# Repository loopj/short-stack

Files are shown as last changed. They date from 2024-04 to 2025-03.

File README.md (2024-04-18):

<div align="center">
  <h1>
    Short Stack
    Short Stack
  </h1>

  <h4>World's Smallest Nintendo Wii, using a trimmed motherboard and custom stacked PCBs</h4>

  <p>
    <a href="#features">Features</a> &middot;
    <a href="#size--scale">Size & Scale</a> &middot;
    <a href="#components">Components</a> &middot;
    <a href="#build-guide">Build Guide</a> &middot;
    <a href="#special-thanks">Special Thanks</a>
  </p>
</div>

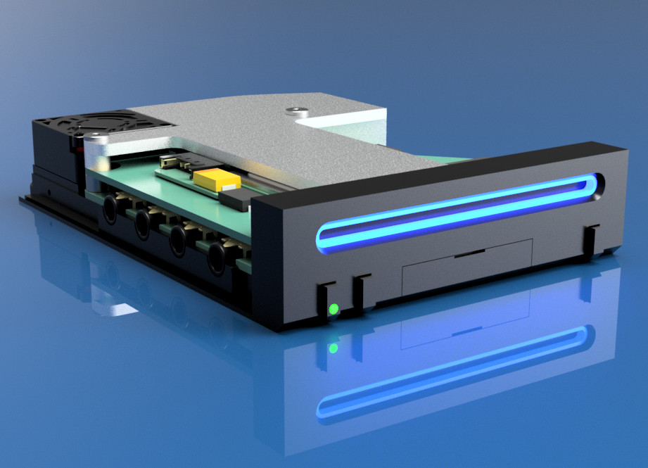
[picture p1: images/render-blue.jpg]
Short Stack Render


## Features

- World's smallest "to scale" Wii console
- Powered by USB-C
- HDMI for lossless digital audio and video (powered by [GCVideo](https://github.com/ikorb/gcvideo))
- Bluetooth for Wii remotes and accessories
- MicroSD card stores games and saves, instead of disc drive & memory cards
- 4 GameCube controller ports
- Power, reset, and sync buttons
- Power indicator LED and iconic blue glowing disc slot
- Soft shutdown, power on/off via Wiimote

## Size & Scale

This is a **1:2.38 scale** model of an original Nintendo Wii console, but since that is hard to visualize here are some other stats:

- Same size as a typical deck of playing cards
- **7.4% the volume** of an original Wii console
- You could fit **13.5** of these inside an original Wii

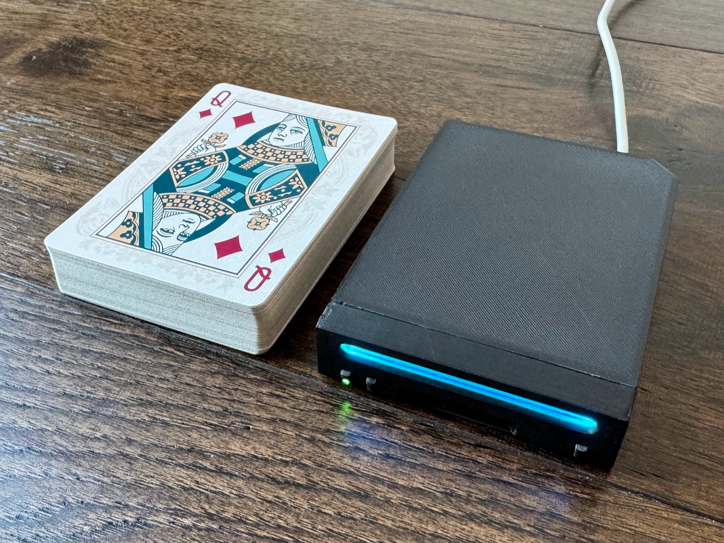
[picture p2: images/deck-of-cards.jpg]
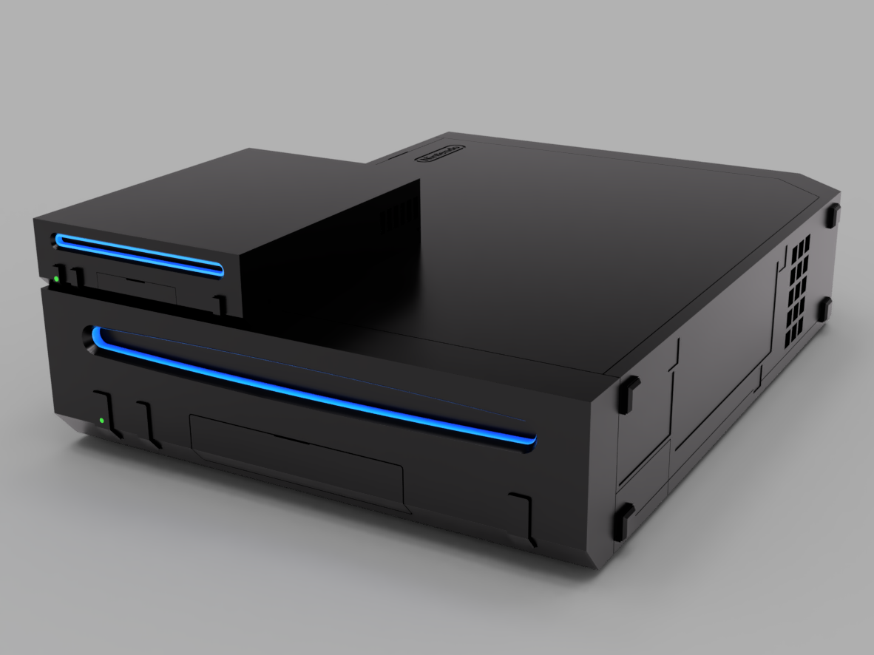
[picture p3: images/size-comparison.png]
 

I'm pretty sure this sets the record for the smallest functional scale-model Wii console, but let me know if I'm wrong!

### Could we go smaller?

Yes! It is definitely possible to go smaller than this. My [version of the Omega trim](images/trim.png) keeps all four main mounting holes, which makes it around 7mm wider than a classic Omega trim. Additionally [Wesk](https://twitter.com/Weskmods) has managed to get a Wii motherboard down to 52x52mm on his final destination trim, which is a a full 10mm narrower than my trim. I estimate you could reduce the volume by a further 25-30% without losing any functionality, but it would be an incredibly tight fit and tricky to assemble.

## Components

As the name implies, *Short Stack* is built from a stack of custom PCBs, and a custom heatsink, that are all designed to fit together in a compact and modular way.

### A modular motherboard

Making a tiny build like this is made possible by trimming the Wii motherboard down to the bare essentials. The result is a board which is just *62x62mm*, but still contains the CPU, GPU, RAM and flash memory.

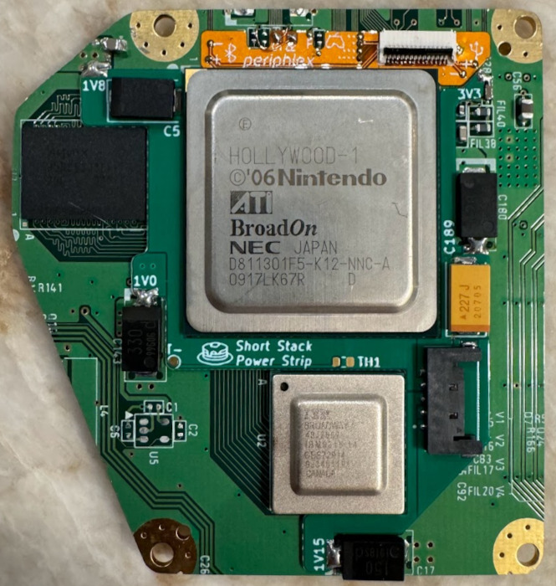
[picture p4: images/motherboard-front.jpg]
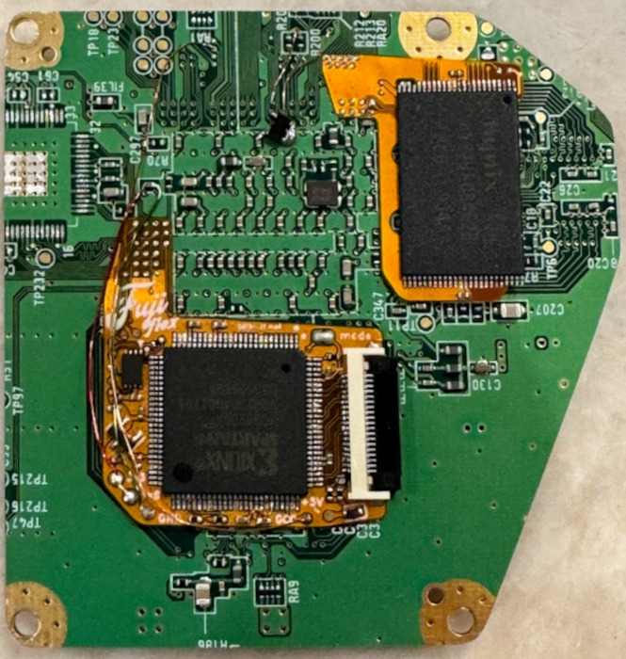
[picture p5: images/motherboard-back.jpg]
 

Since we removed the original power circuitry and trimmed off the USB, Bluetooth, and GameCube connectors, we need to provide power and data to the board another way. I designed a couple of boards which solder directly to the front of a trimmed Wii motherboard to provide power and data, which help avoid a tangled mess of wires.

The [Wii Power Strip](https://github.com/loopj/wii-power-strip) supplies power to the Wii motherboards using a Molex Pico-Lock connector, and additionally has footprints to help relocate of a couple of capacitors which are typically removed when trimming a Wii.

[Periphlex](https://github.com/loopj/periphlex) is a flex PCB which breaks out the Bluetooth, USB and GameCube controller data lines, as well as the power, shutdown, and reset GPIOs. These are then made available via a 14-pin FFC connector. This approach replaces 11 magnet wires with a single, removable ribbon cable.

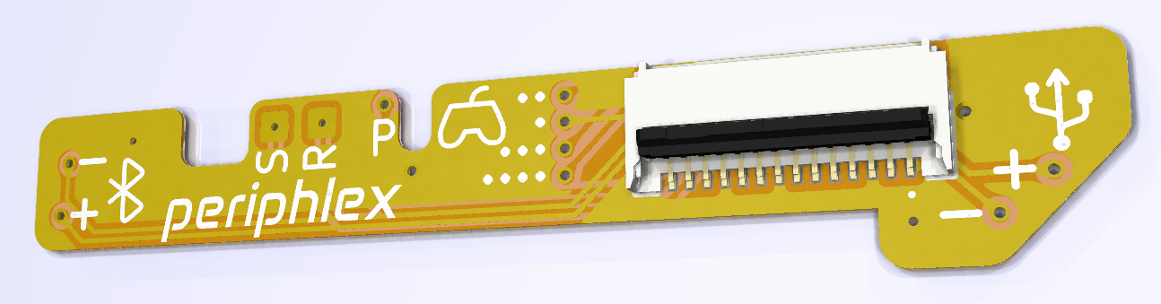
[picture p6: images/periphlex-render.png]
Periphlex


On the back of the motherboard, I'm using two open-source boards designed by the very talented [YveltalGriffin](https://github.com/mackieks). [fujiflex](https://github.com/mackieks/fujiflex) provides digital A/V output using GCVideo, and [nandFlex](https://github.com/mackieks/nandFlex) relocates the Wii's NAND memory chip, to enable the tight trim.

### Custom PCBs

In addition to the modular boards on the motherboard, I designed two PCBs specific to Short Stack which provide the rest of the functionality for the console.

The *main board* PCB hosts the power regulators, USB to microSD logic, HDMI connector, GameCube ports, and a microcontroller for power management. A 14-pin ribbon cable connects this board to the Wii motherboard via *Periphlex*, and a power cable delivers power to the *Power Strip*.

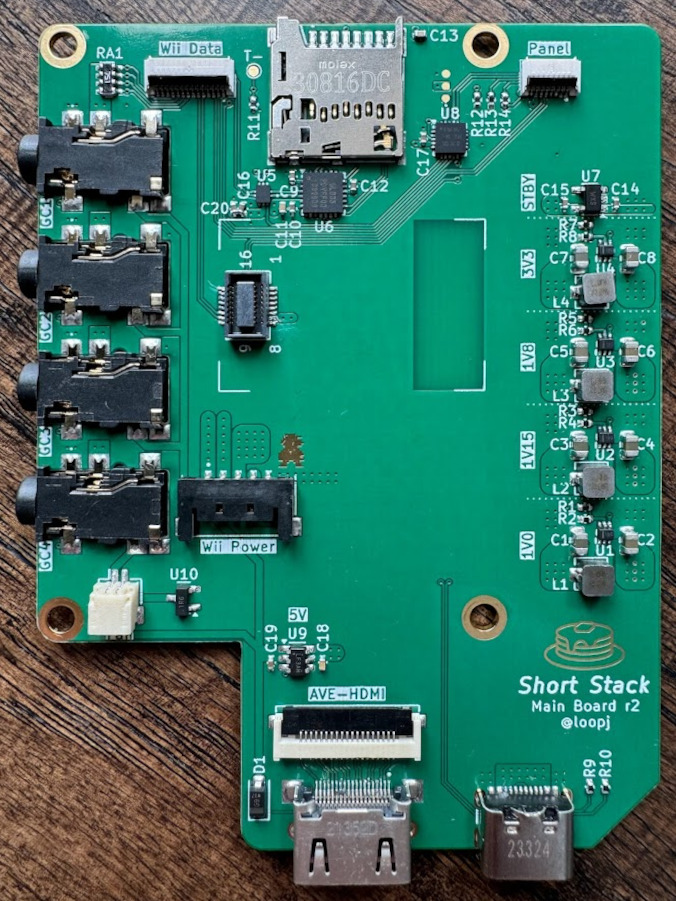
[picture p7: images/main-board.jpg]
Main Board


The *front panel* PCB hosts the power, reset, and sync buttons, as well as the power LED and disc slot LEDs. This board connects to the main board via a short 8-pin ribbon cable.

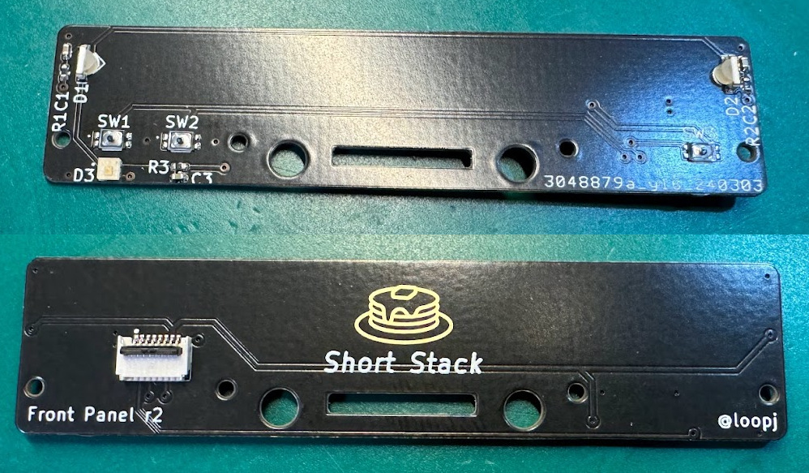
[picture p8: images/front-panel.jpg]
Front Panel Board


Since the GameCube controller connectors on the original Wii wouldn't fit cleanly on a build of this size, I use TRRS headphone connectors instead. This is the exact same approach used on the amazing [GC Nano](https://bitbuilt.net/forums/index.php?threads/gc-nano-the-worlds-smallest-gamecube.5697/) and in fact I made sure the dongles are pinout compatible!

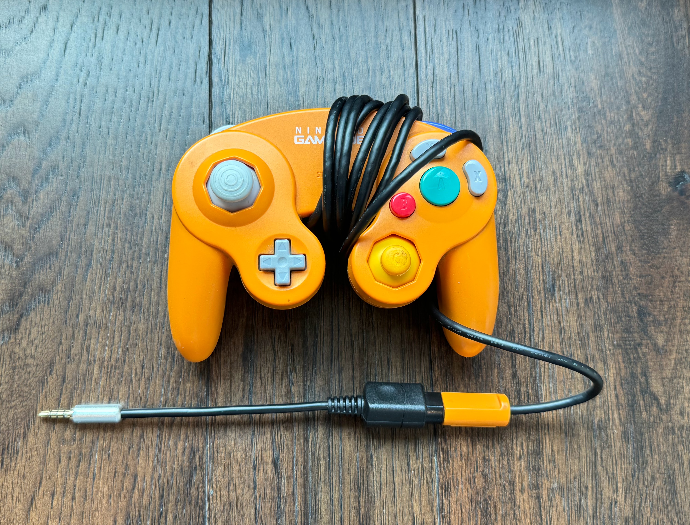
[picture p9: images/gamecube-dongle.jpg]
GameCube dongle


### Cooling

The final part of the "stack" is a custom heatsink which is designed to be as low profile as possible, while still providing adequate cooling for the Wii's CPU and GPU. The heatsink is designed to be machined from aluminum or copper, and incorporates mounting holes which align with those on the Wii motherboard.

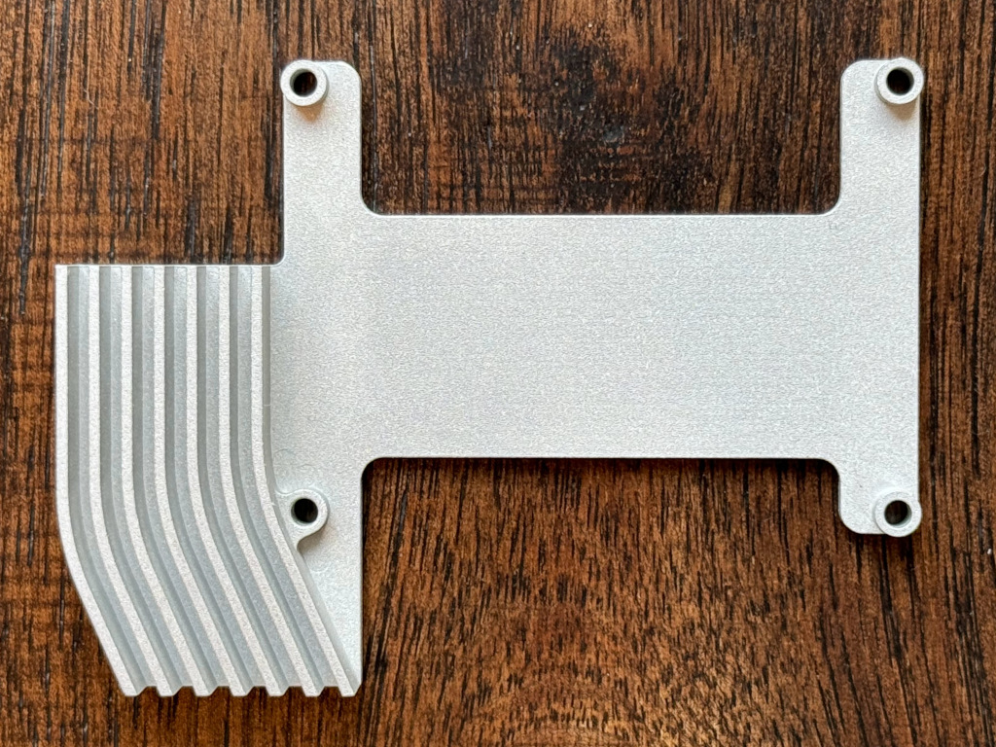
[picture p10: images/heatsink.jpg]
Heatsink


I managed to find a tiny 5V blower fan ([Pelonis AGB208N](https://catalog.pelonistechnologies.com/item/air-g-series-micro-fans-and-micro-blowers/micro-fans-and-micro-blowers/agb208n)) which measures just 20x20x8mm and somehow puts out 0.84 CFM of air. This blows air through the heatsink fins, out the side of the case.

### Case

The stack is housed in a custom 3D printed case, secured with four M2.5 screws and spacers. The rest of case is assembled using self-tapping M1.2 screws. The screw locations and fan vents are positioned to match the original Wii case as closely as possible, to minimize visible screws.

You can access files on the SD card by connecting the console to a computer via USB, but I also included an access panel on the front of the case where the original Wii SD card slot is found. This panel is held in place by magnets and can be removed to access the SD card without opening the case. Shout out to Wesk for the magnet idea!

To keep the clean aesthetic of the original Wii I wanted to hide the GameCube controller ports behind a panel. I always hated the hinged design of the original, and it is quite difficult to replicate at this scale, so I redesigned this panel to be a sliding panel.

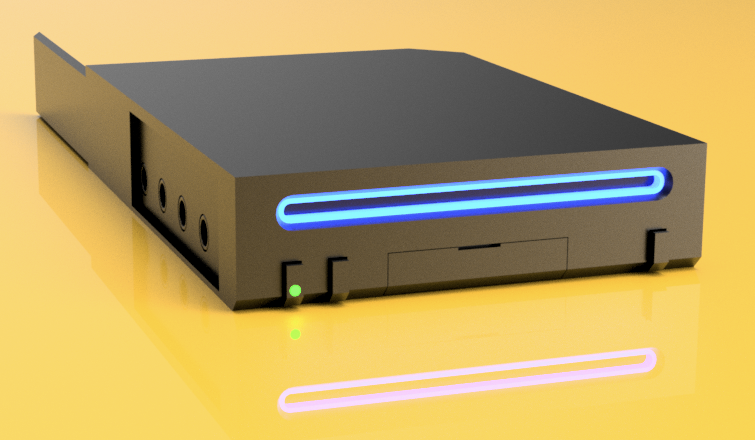
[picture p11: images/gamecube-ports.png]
GameCube Ports


The Wii's iconic disc slot lights are recreated using a 1.5mm thick custom cut acrylic light diffuser, which is illuminated by two side-mounted addressable LEDs on the front panel board. The power, reset, and sync buttons are all also 3D printed, and the power button hosts a tiny light pipe to allow the power LED to shine through.

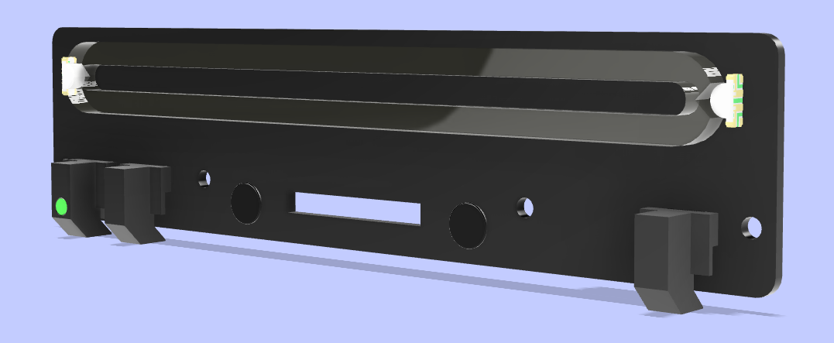
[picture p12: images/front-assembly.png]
Front assembly


I FDM printed the case on a Voron 2.4 in ABS using a 0.4mm nozzle at 0.1mm layer height, but it should print fine in PLA or PETG on a well-tuned printer. At this scale, dimensional accuracy is important. In theory it should be possible to print this on an SLA printer, but I haven't tried it.

## Build Guide

> [!CAUTION]
> This is not a beginner project! This build requires performing a challenging motherboard trim, fine pitch soldering, and PCB assembly. If you are not comfortable with these tasks, I would recommend starting with a simpler project and working your way up - check out the [BitBuilt forums](https://bitbuilt.net) for some awesome project worklogs.

### What you'll need

- 4-layer Wii motherboard
- [nandFlex](https://github.com/mackieks/nandFlex) board (or [4Layer Technologies RVL-NAND](https://4layertech.com/products/rvl-nand-flex-board-pack-of-2))
- Assembled [fujiflex](https://github.com/mackieks/fujiflex) (or [ElectronAVE](https://electron-shepherd.com/products/electronave-kit))
- Assembled [Wii Power Strip](https://github.com/loopj/wii-power-strip/tree/r1) - **must be revision 1!**
- Assembled [Periphlex](https://github.com/loopj/periphlex)
- [Short Stack main board](main-board/KiCad) - 1.2mm thickness, stencil recommended
- [Short Stack front panel](front-panel/KiCad) - 0.8mm thickness, black soldermask, stencil recommended
- [Heatsink](case/heatsink.step) - machined from aluminum or copper
- [Light diffuser](case/disc-light-diffuser.dxf) - cut from 1.5mm thick acrylic
- The components and hardware from the [bill of materials](full-bom.xlsx)

### Assembly

Case Exploded

- Assemble main board and front panel PCBs
  - I recommend using a solder stencil and a hot plate or reflow oven
  - If using a hot plate, hand solder the headphone connectors after reflowing the rest of the components
  - Secure two 3 x 1mm magnets inside the holes on the front panel board using a dab of CA glue
- Flash the [main board firmware](main-board/firmware)
- Prepare and trim the Wii motherboard
  - Relocate the NAND, test it still boots
  - Perform a wireless U10 relocation, test it still boots - you may wish to wire a magnet wire to the [`SHUTDOWN` via](https://bitbuilt.net/forums/index.php?threads/soft-shutdown-power-on-via-bluetooth.6239/) first
  - Install fujiflex, and test digital A/V output works
  - Trim the motherboard (see [trim dimensions](images/trim.png))
- Assemble and install *Power Strip* ([see instructions](https://github.com/loopj/wii-power-strip/tree/r1#installation))
- Assemble and install *Periphlex* ([see instructions](https://github.com/loopj/periphlex#installation))
- Connect the boards
  - Connect the main board to the motherboard via a 14-pin FFC cable to *Periphlex*
  - Connect the main board to the motherboard via a 5-pin Molex Pico-Lock cable to *Power Strip*
  - Connect the front panel board to the main board via an 8-pin FFC cable
  - Connect the fan to the main board
  - Apply thermal paste to the CPU and GPU
  - Stack the components: heatsink, motherboard, M2.5 x 3mm spacers, main board
  - Install the stack to the case bottom using M2.5 x 12mm wafer head screws
- Secure the top of the case to the bottom using four M1.2 x 4mm screws
- Secure the front panel PCB to the front of the case using two M1.2 x 3mm screws
- Secure the front of the case to the bottom of the case using two M1.2 x 4mm screws
- Press-fit two 3 x 1mm magnets into the holes on the sd card cover, make sure they match polarity with the magnets on the front panel PCB
- Slide the side panel into the case

## Special Thanks

This project would not be possible without the amazing [BitBuilt community](https://bitbuilt.net), I'm truly standing on the shoulders of giants here.

In particular, I'd like to thank:

- [Wesk](https://twitter.com/Weskmods) for setting the bar so high with renders, for the suggestion of using magnets in the case assembly, and for the inspirational GC Nano
- [Aurelio](https://twitter.com/aureliomannara) for pointing me in the right direction to help figure the soft shutdown and power on via Wiimote.
- [YveltalGriffin](https://twitter.com/YveltalGriffin) for PCB design feedback, helping me when I was documenting the bluetooth module, and of course for fujiflex and nandFlex
- [CrazyGadget](https://twitter.com/crazygadgetmods) for helping me fix my GL823K on the first revision of my boards, and for the inspirational GC Nano
- [Y2K](https://twitter.com/y2k_x38) and supertazon for joining the PCB assembly live stream and being super supportive

## License

Permissively released under the Solderpad Hardware License v2.1

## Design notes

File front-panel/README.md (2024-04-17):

# Short Stack Front Panel

This folder contains the KiCad schematic and PCB layout for the Short Stack front panel PCB.

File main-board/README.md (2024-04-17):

# Short Stack Main Board

The folder contains the KiCad schematic, pcb layouts, and firmware for the Short Stack main PCB.

## Future enhancements

- [ ] Dual load switch per GC line to allow hotplug (TPS22960 or similar)
- [ ] Potentially drop the 5V load switch if we are load switching each GC controller
- [ ] Hang bluetooth antenna off right edge of board

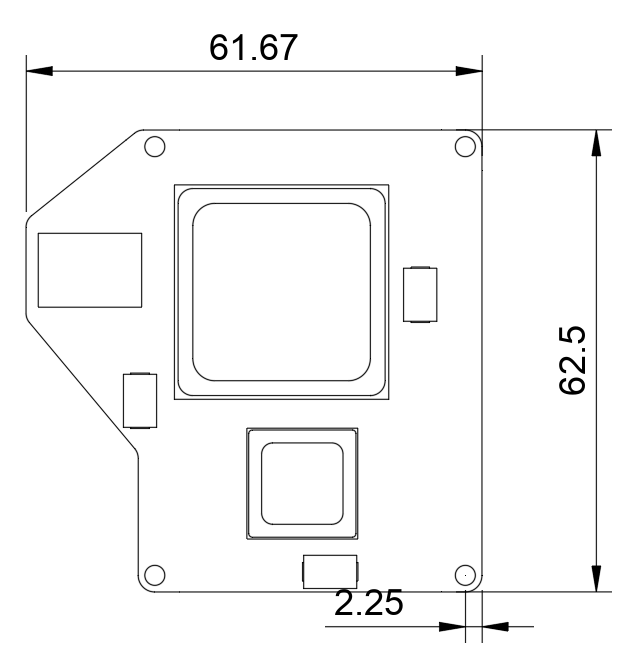
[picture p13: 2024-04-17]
images/trim.png

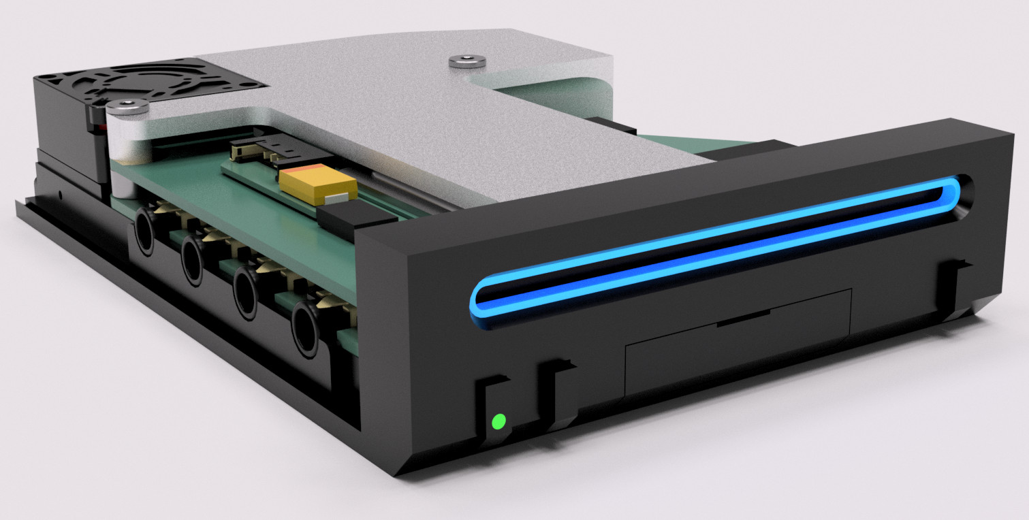
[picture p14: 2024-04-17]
images/render.jpg

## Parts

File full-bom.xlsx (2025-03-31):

Board | Reference | Description | Qty | Manufacturer Part Number | Digi-Key Part #
Main Board | C1,C3,C5,C7 | CAP CER 22UF 6.3V X5R 0805 | 4 | CL21A226MQQNNNE | 1276-1100-1-ND
 | C2,C4,C6,C8 | CAP CER 10UF 16V X5R 0805 | 4 | CL21A106KOQNNNE | 1276-1096-1-ND
 | C9,C12,C14,C15,C16 | CAP CER 1UF 6.3V X7R 0402 | 5 | GRM155R70J105KA12J | 490-13339-1-ND
 | C10,C17,C19,C20 | CAP CER 0.1UF 25V X7R 0402 | 4 | GRM155R71E104KE14J | 490-14603-1-ND
 | C11,C13,C18 | CAP CER 4.7UF 6.3V X5R 0402 | 3 | GRM155R60J475ME87D | 490-5408-1-ND
 | D1 | DIODE SCHOTTKY 30V 200MA SOD123 | 1 | BAT54GWJ | 1727-7328-1-ND
 | J1,J2,J3,J4 | CONN JACK 4COND 3.5MM SMD R/A | 4 | SJ-43504 | CP-43504SJCT-ND
 | J5 | CONN HEADER SMD R/A 5POS 1.5MM | 1 | 5040500591 | WM24877CT-ND
 | J6 | CONN FFC FPC 14POS 0.5MM R/A | 1 | 5034801400 | WM1442CT-ND
 | J7 | CONN RCPT 16POS SMD GOLD | 1 | 541020164 | WM8876CT-ND
 | J8 | CONN RCP USB2.0 TYP C 24P SMD RA | 1 | 2171790001 | 900-2171790001CT-ND
 | J9 | CONN FFC BOTTOM 19POS 0.5MM R/A | 1 | 5052781933 | 900-5052781933CT-ND
 | J10 | CONN RCPT MINI HDMI 19POS SMD RA | 1 | 2013978-1 | A107963CT-ND
 | J11 | MICRO SD PUSH/PUSH SMALL 8C | 1 | 5033981892 | WM11190CT-ND
 | J12 | CONN FFC FPC 8POS 0.5MM R/A | 1 | 5034800800 | WM1388CT-ND
 | J13 | CONN HEADER SMD R/A 2POS 1MM | 1 | SM02B-SRSS-TB | 455-SM02B-SRSS-TBCT-ND
 | L1,L2,L3,L4 | FIXED IND 1UH 5A 24 MOHM SMD | 4 | IHLP1212BZER1R0M11 | 541-1319-1-ND
 | R1 | RES 66.5K OHM 1% 1/16W 0402 | 1 | RC0402FR-0766K5L | YAG3209CT-ND
 | R2,R4,R6,R8 | RES 100K OHM 1% 1/16W 0402 | 4 | RC0402FR-07100KL | 311-100KLRCT-ND
 | R3 | RES 91K OHM 1% 1/16W 0402 | 1 | RC0402FR-1391KL | 13-RC0402FR-1391KLCT-ND
 | R5 | RES 200K OHM 1% 1/16W 0402 | 1 | RC0402FR-07200KL | 311-200KLRCT-ND
 | R7 | RES 453K OHM 1% 1/16W 0402 | 1 | RC0402FR-07453KL | YAG3164CT-ND
 | R9,R10 | RES 5.1K OHM 1% 1/16W 0402 | 2 | RC0402FR-075K1L | 311-5.10KLRCT-ND
 | R11 | RES 2.2K OHM 1% 1/16W 0402 | 1 | RC0402FR-072K2L | 311-2.20KLRCT-ND
 | R12,R13,R14 | RES 10K OHM 1% 1/16W 0402 | 3 | RC0402FR-0710KL | 311-10.0KLRCT-ND
 | RA1 | RES ARRAY 4 RES 750 OHM 1206 | 1 | YC164-JR-07750RL | 13-YC164-JR-07750RLCT-ND
 | U1,U2,U3,U4 | IC REG BUCK ADJ 3A SOT5X3 | 4 | TLV62585DRLR | 296-51694-1-ND
 | U5 | IC SWITCH DPDT X 1 8OHM 10UQFN | 1 | TMUXHS221NKGR | 296-TMUXHS221NKGRCT-ND
 | U6 | USB SD CARD READER CONTROLLER | 1 | GL835 | - | https://www.aliexpress.us/item/3256805688846173.html
 | U7 | IC REG LINEAR 3.3V 300MA SOT23-5 | 1 | MIC5504-3.3YM5-TR | 576-4764-1-ND
 | U8 | IC MCU 8BIT 16KB FLASH 20VQFN | 1 | ATTINY1616-MNR | ATTINY1616-MNRCT-ND
 | U9 | IC PWR SWTCH N-CHAN 1:1 TSOT23-6 | 1 | SIP32510DT-T1-GE3 | SIP32510DT-T1-GE3CT-ND
 | U10 | IC PWR DRIVER BIPOLAR 1:1 SOT23 | 1 | DRDC3105F-7 | DRDC3105F-7DICT-ND
Front Panel | C1,C2,C3 | CAP CER 0.1UF 25V X7R 0402 | 3 | GRM155R71E104KE14J | 490-14603-1-ND
 | D1,D2 | ADDRESS LED DISCRETE SERIAL RGB | 2 | 12-23C/RSGHBHW-5V01/2C | 1080-1624-1-ND
 | D3 | ADDRESS LED RED/GREEN/BLUE | 1 | 19-C47/RSGHBHC-5V01/2T | 1080-1623-1-ND
 | J1 | CONN FFC FPC 8POS 0.5MM R/A | 1 | 5034800800 | WM1388CT-ND
 | R1,R2,R3 | RES 33 OHM 1% 1/16W 0402 | 3 | RC0402FR-0733RL | 311-33.0LRCT-ND
 | SW1,SW2,SW3 | SWITCH TACTILE SPST-NO 0.02A 15V | 3 | R-668048 | 2508-R-668048CT-ND
Thermal |  | FAN MICR BLOWER 20X8MM 5VDC WIRE | 1 | RFB2008N | - | https://www.aliexpress.us/item/3256805475387171.html
 |  | JST-SH 2POS Connector or Pre-crimped Cable |  |  |  | Either crimp a JST-SH connector directly to the fan cable, or buy something like https://www.amazon.com/BOJOUL-JST-SH-1-0mm-Pin
 |  | Thermal Paste |  |  |  | Any thermal paste will work
Cables |  | CABLE FFC/FPC 14POS 0.5MM 1.18" | 1 | 05-14-A-0030-A-4-06-4-T | 2073-05-14-A-0030-A-4-06-4-T-ND | Can find much cheaper on AliExpress or eBay
 |  | CABLE FFC/FPC 8POS 0.5MM 1.18" | 1 | 05-08-D-0030-A-4-06-4-T | 2073-05-08-D-0030-A-4-06-4-T-ND | Can find much cheaper on AliExpress or eBay
 |  | CABLE FFC/FPC 19POS 0.5MM 3.98" |  | 05-19-A-0101-A-4-06-4-T | 2073-05-19-A-0101-A-4-06-4-T-ND | Can find much cheaper on AliExpress or eBay
 |  | CABLE ASSY PICOLOCK 5 POS 50MM | 1 | 151320500 | WM16717-ND | Alternatively - crimp your own cables to reduce BOM cost
Controller Dongles |  | GameCube extension cable | 4 |  |  | https://www.aliexpress.us/item/3256805500189218.html or https://www.amazon.com/dp/B09W9557WT
 |  | TRRS headphone jack | 4 |  |  | https://www.aliexpress.us/item/3256805371689272.html or https://www.amazon.com/dp/B08YY59B3N
Fasteners, etc |  | M2.5 x 3mm Spacers | 4 |  |  | https://www.amazon.com/INJORA-Washers-Spacers-Stainless-Spacers/dp/B0CBWZYJ2K
 |  | M2.5 x 12mm Wafer Head Screws | 4 |  |  | https://www.amazon.com/dp/B0BF5YX36H
 |  | M1.2 x 4mm Flat Head Self Tapping Screws | 6 |  |  | https://www.amazon.com/uxcell-Stainless-Phillips-Tapping-Screws/dp/B01LZQ042N
 |  | M1.2 x 3mm Round Head Self Tapping Screws | 2 |  |  | https://www.amazon.com/dp/B01M1CI4PA
 |  | 3mm x 1mm Magnets | 4 |  |  | https://www.amazon.com/TRYMAG-Miniature-Magnets-Neodymium-Whiteboard/dp/B09SLG3KSW
 |  | LIGHT PIPE PNL MNT 1MM RND .100" | 1 | PLPC1-100 | 492-1972-ND

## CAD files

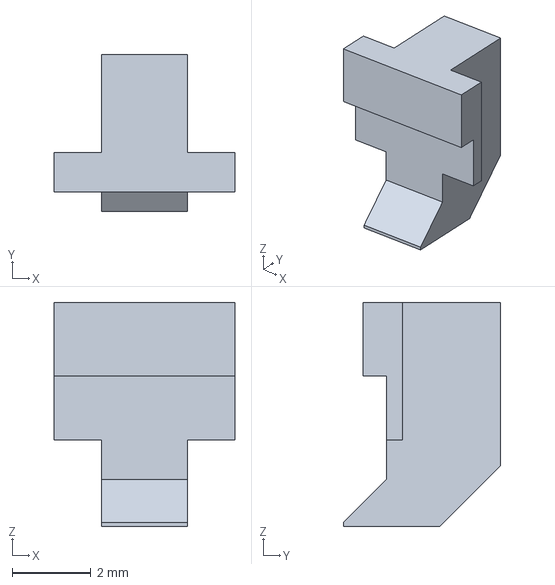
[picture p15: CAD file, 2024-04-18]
case/button.step
4.60 x 4.00 x 5.70 mm

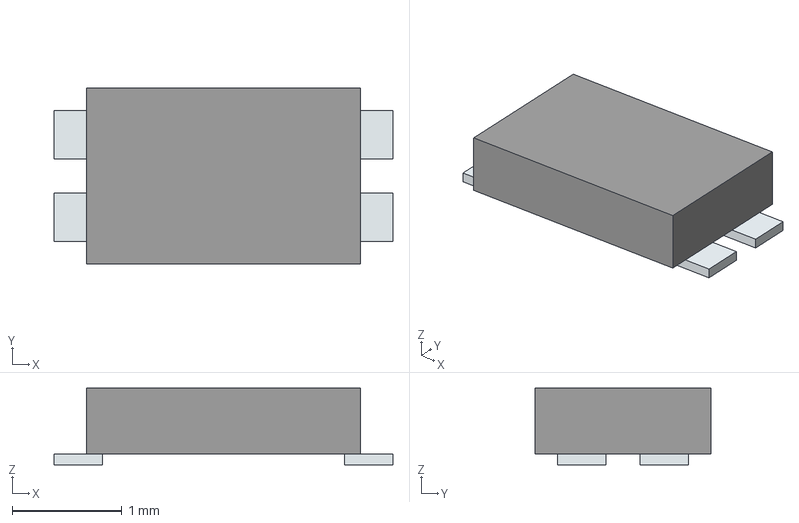
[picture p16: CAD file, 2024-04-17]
front-panel/KiCad/project-footprints/R-668048.stp
3.09 x 1.60 x 0.7 mm
Pins

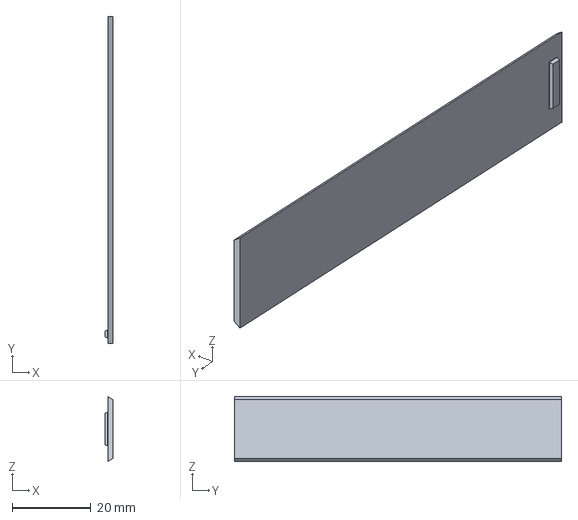
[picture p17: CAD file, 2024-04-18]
case/case-side.step
1.90 x 82.8 x 16.5 mm

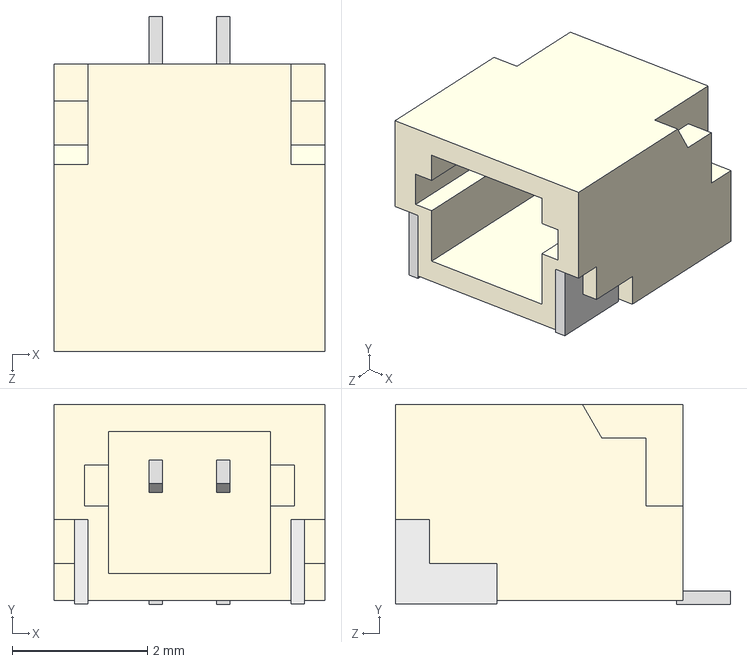
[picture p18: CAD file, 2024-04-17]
main-board/KiCad/project-footprints/SM02B-SRSS-TB_LF__SN_.stp
4.00 x 2.96 x 4.95 mm

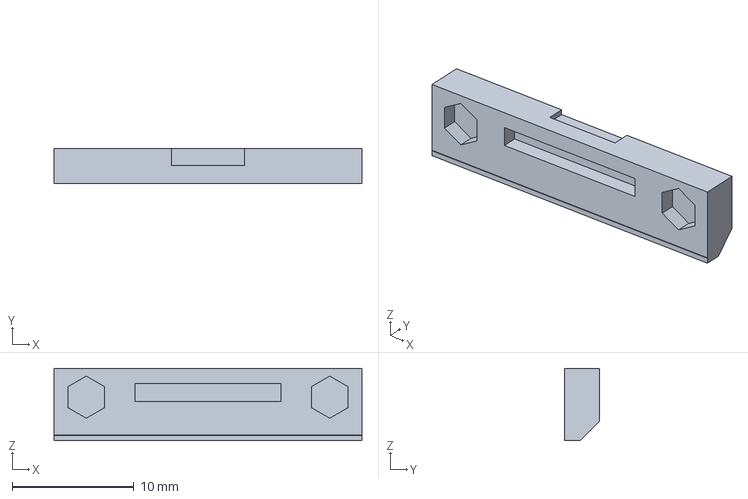
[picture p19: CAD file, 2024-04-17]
case/sd-card-cover.step
25.3 x 2.89 x 5.95 mm

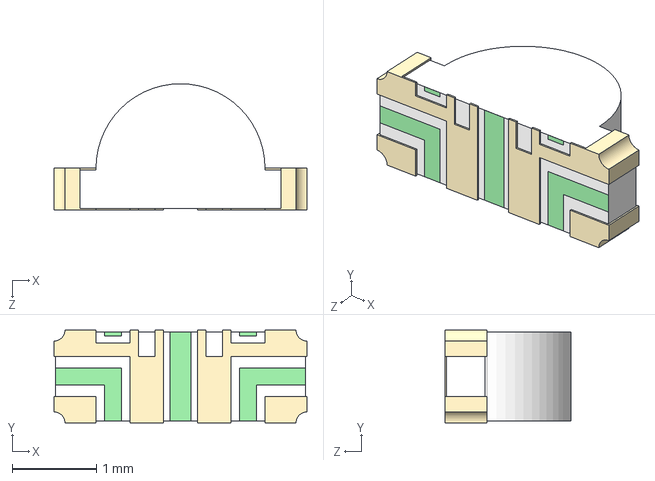
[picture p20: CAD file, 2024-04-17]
front-panel/KiCad/project-footprints/12-23C_RSGHBHW-5V01_2C.step
3.00 x 1.10 x 1.50 mm

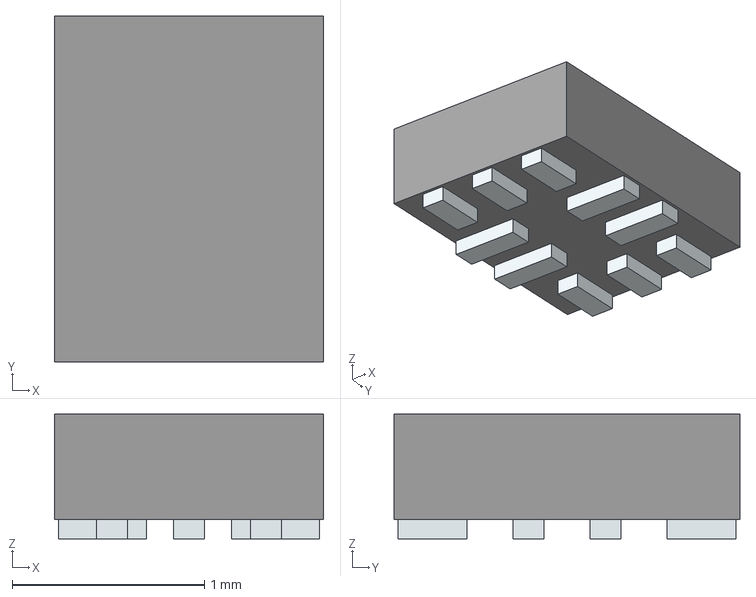
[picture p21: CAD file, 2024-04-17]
main-board/KiCad/project-footprints/TMUXHS221NKGR.stp
1.40 x 1.80 x 0.65 mm
Pins

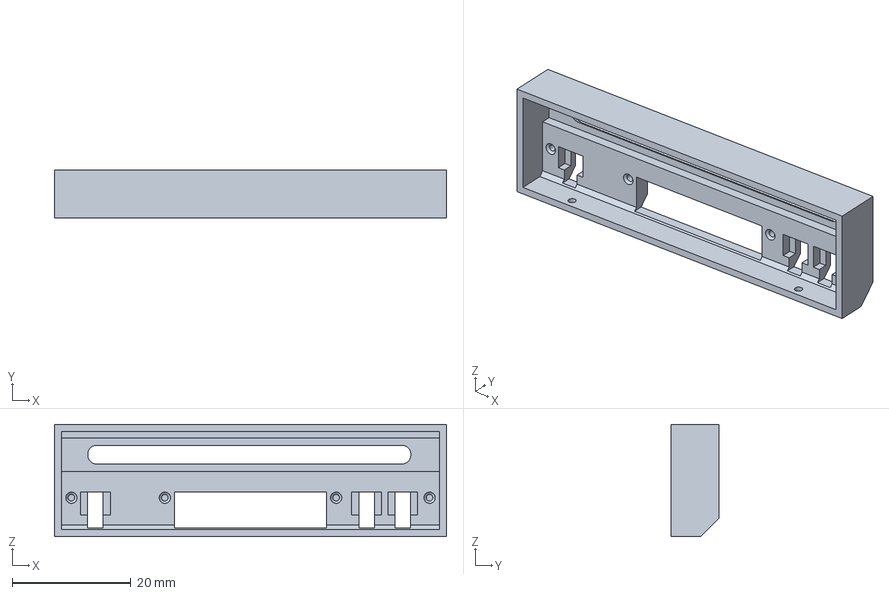
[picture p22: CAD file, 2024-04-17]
case/case-front.step
65.9 x 8.00 x 18.9 mm

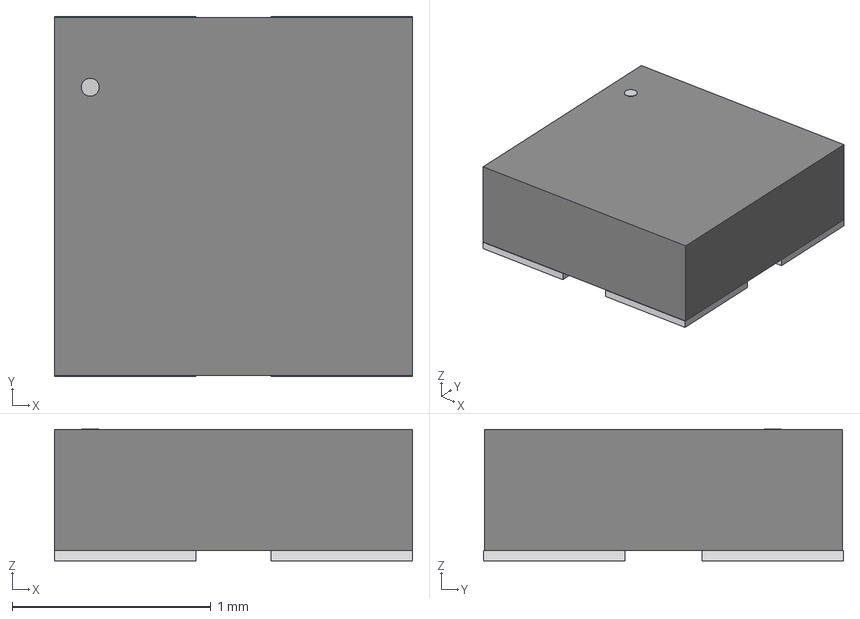
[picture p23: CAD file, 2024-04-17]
front-panel/KiCad/project-footprints/19-C47RSGHBHC-5V012T_EVE.step
1.80 x 1.81 x 0.663 mm

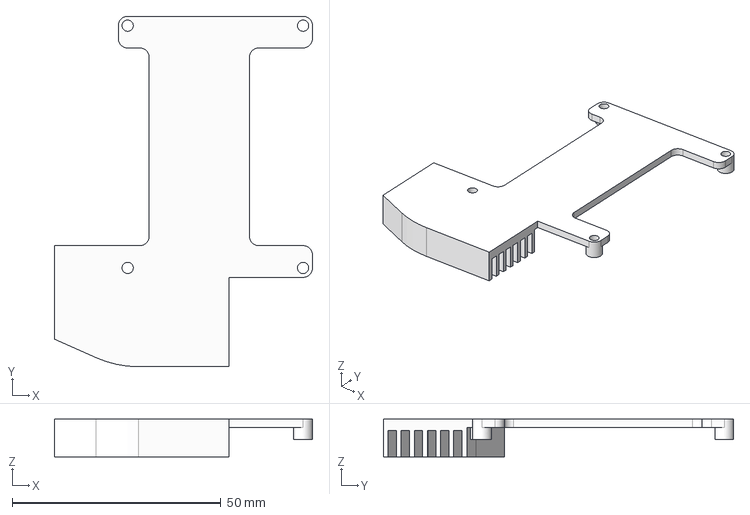
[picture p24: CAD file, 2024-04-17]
case/heatsink.step
61.8 x 83.9 x 9.00 mm

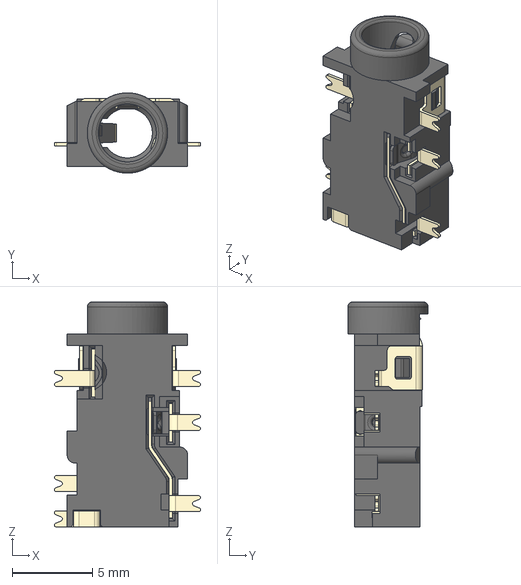
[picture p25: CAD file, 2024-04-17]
main-board/KiCad/project-footprints/SJ-43504-SMT-TR.step
9.10 x 5.00 x 14.0 mm

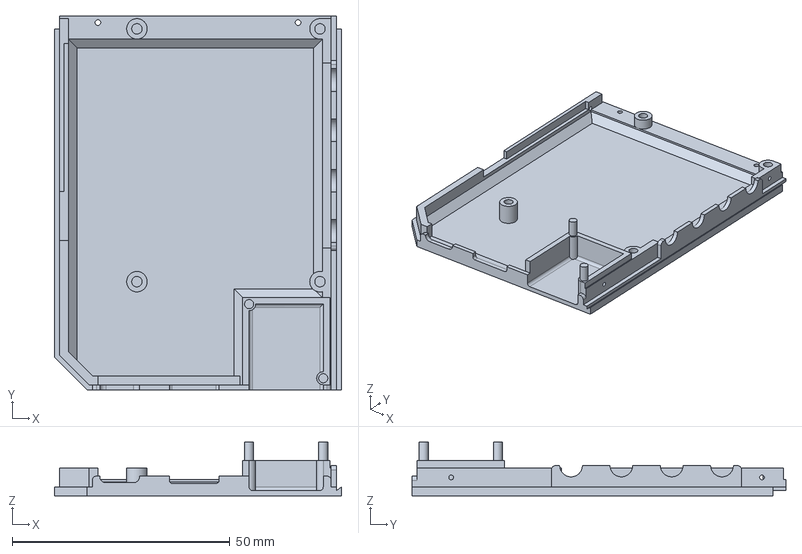
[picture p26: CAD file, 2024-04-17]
case/case-bottom.step
65.9 x 85.8 x 12.3 mm

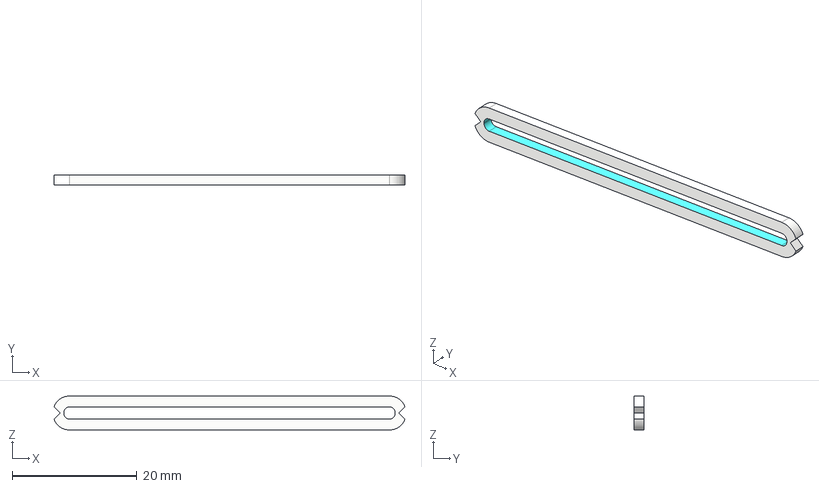
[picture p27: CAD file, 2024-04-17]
case/disc-light-diffuser.step
56.3 x 1.59 x 5.45 mm

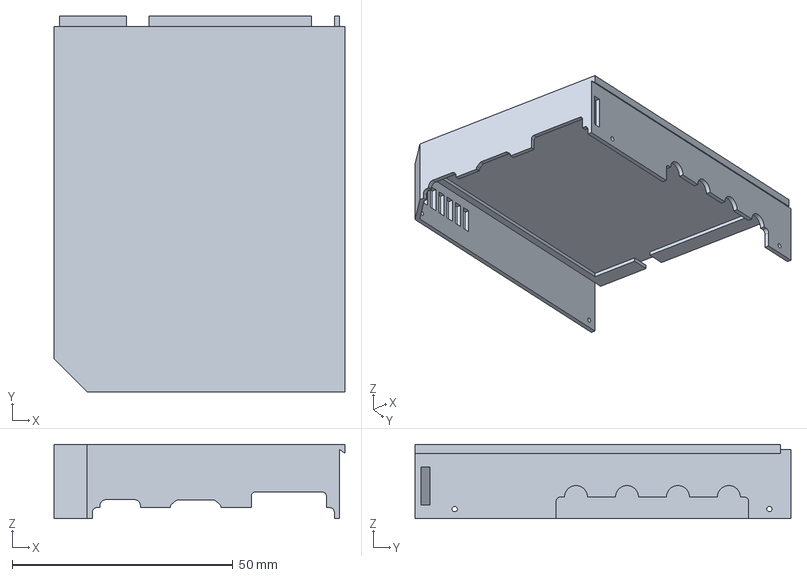
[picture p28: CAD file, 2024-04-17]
case/case-top.step
65.9 x 85.2 x 16.9 mm

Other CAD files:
main-board/KiCad/project-footprints/SOT-523.step
main-board/KiCad/project-footprints/IND_A220M11_VIS.step
main-board/KiCad/project-footprints/504050-0591.stp
front-panel/KiCad/project-footprints/5034800800.stp
case/disc-light-diffuser.dxf
main-board/KiCad/project-footprints/2013978-1.stp
main-board/KiCad/project-footprints/2171790001.step
main-board/KiCad/project-footprints/503398-1892.stp
main-board/KiCad/project-footprints/5034800800.stp
main-board/KiCad/project-footprints/5034801400.stp
main-board/KiCad/project-footprints/505278-1933.stp
main-board/KiCad/project-footprints/541020164.step
main-board/KiCad/project-footprints/TLV62585DRLT.stp

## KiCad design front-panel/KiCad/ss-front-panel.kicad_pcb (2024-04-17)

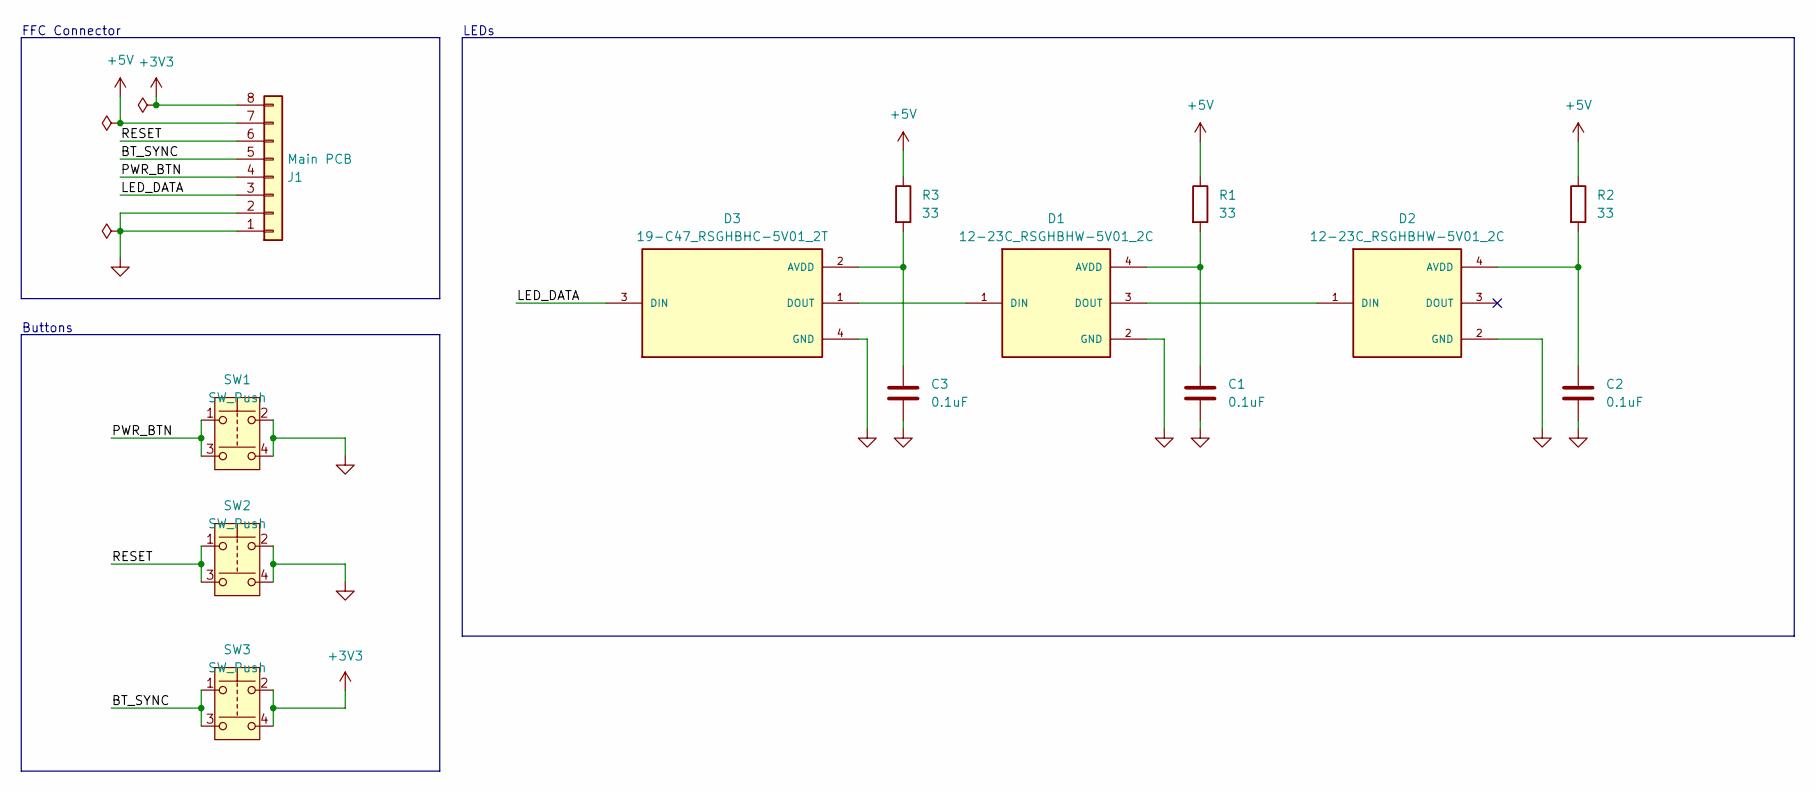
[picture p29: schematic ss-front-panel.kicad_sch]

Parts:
C1, C2, C3: 0.1uF; C_0402_1005Metric
D1, D2: 12-23C_RSGHBHW-5V01_2C; LED_12-23C_RSGHBHW-5V01_2C; MPN 12-23C/RSGHBHW-5V01/2C; Digi-Key Part # 1080-1624-1-ND
D3: 19-C47_RSGHBHC-5V01_2T; LED_19-C47_RSGHBHC-5V01_2T; MPN 19-C47/RSGHBHC-5V01/2T; Digi-Key Part # 1080-1623-1-ND
J1: Main PCB; 5034800800; MPN 5014610891; Digi-Key Part # WM14413CT-ND
R1, R2, R3: 33; R_0402_1005Metric
SW1, SW2, SW3: SW_Push; R668048; MPN R-668048; Digi-Key Part # 2508-R-668048CT-ND

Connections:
+3V3: J1.8, SW3.2, SW3.4
+5V: J1.7, R1.1, R2.1, R3.1
/BT_SYNC: J1.5, SW3.1, SW3.3
/LED_DATA: D3.3 (DIN), J1.3
/PWR_BTN: J1.4, SW1.1, SW1.3
/RESET: J1.6, SW2.1, SW2.3
GND: C1.2, C2.2, C3.2, D1.2 (GND), D2.2 (GND), D3.4 (GND), J1.1, J1.2, SW1.2, SW1.4, SW2.2, SW2.4
unnamed: C1.1, D1.4 (AVDD), R1.2
unnamed: D1.1 (DIN), D3.1 (DOUT)
unnamed: D1.3 (DOUT), D2.1 (DIN)
unnamed: C2.1, D2.4 (AVDD), R2.2
unnamed: C3.1, D3.2 (AVDD), R3.2

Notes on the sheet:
FFC Connector
Buttons
LEDs

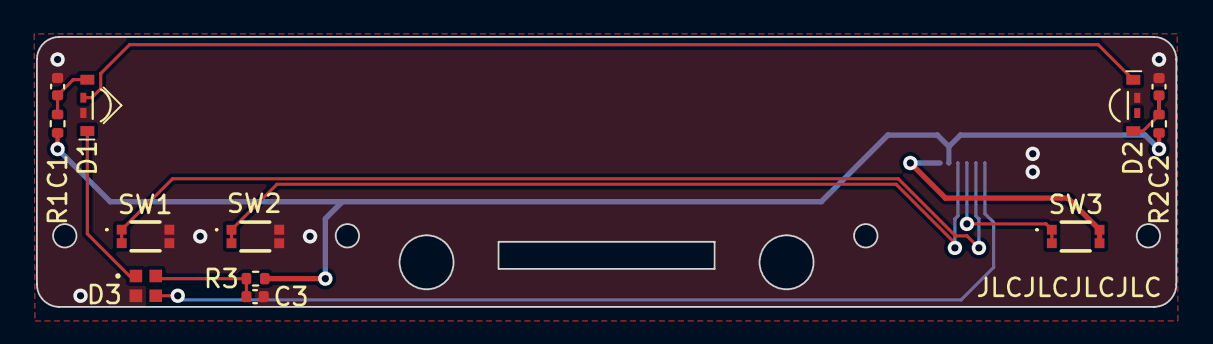
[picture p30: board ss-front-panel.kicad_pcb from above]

Board: 2 copper layers, 63.3 x 15.0 mm, 13 parts (1 on the bottom side), 12 nets.

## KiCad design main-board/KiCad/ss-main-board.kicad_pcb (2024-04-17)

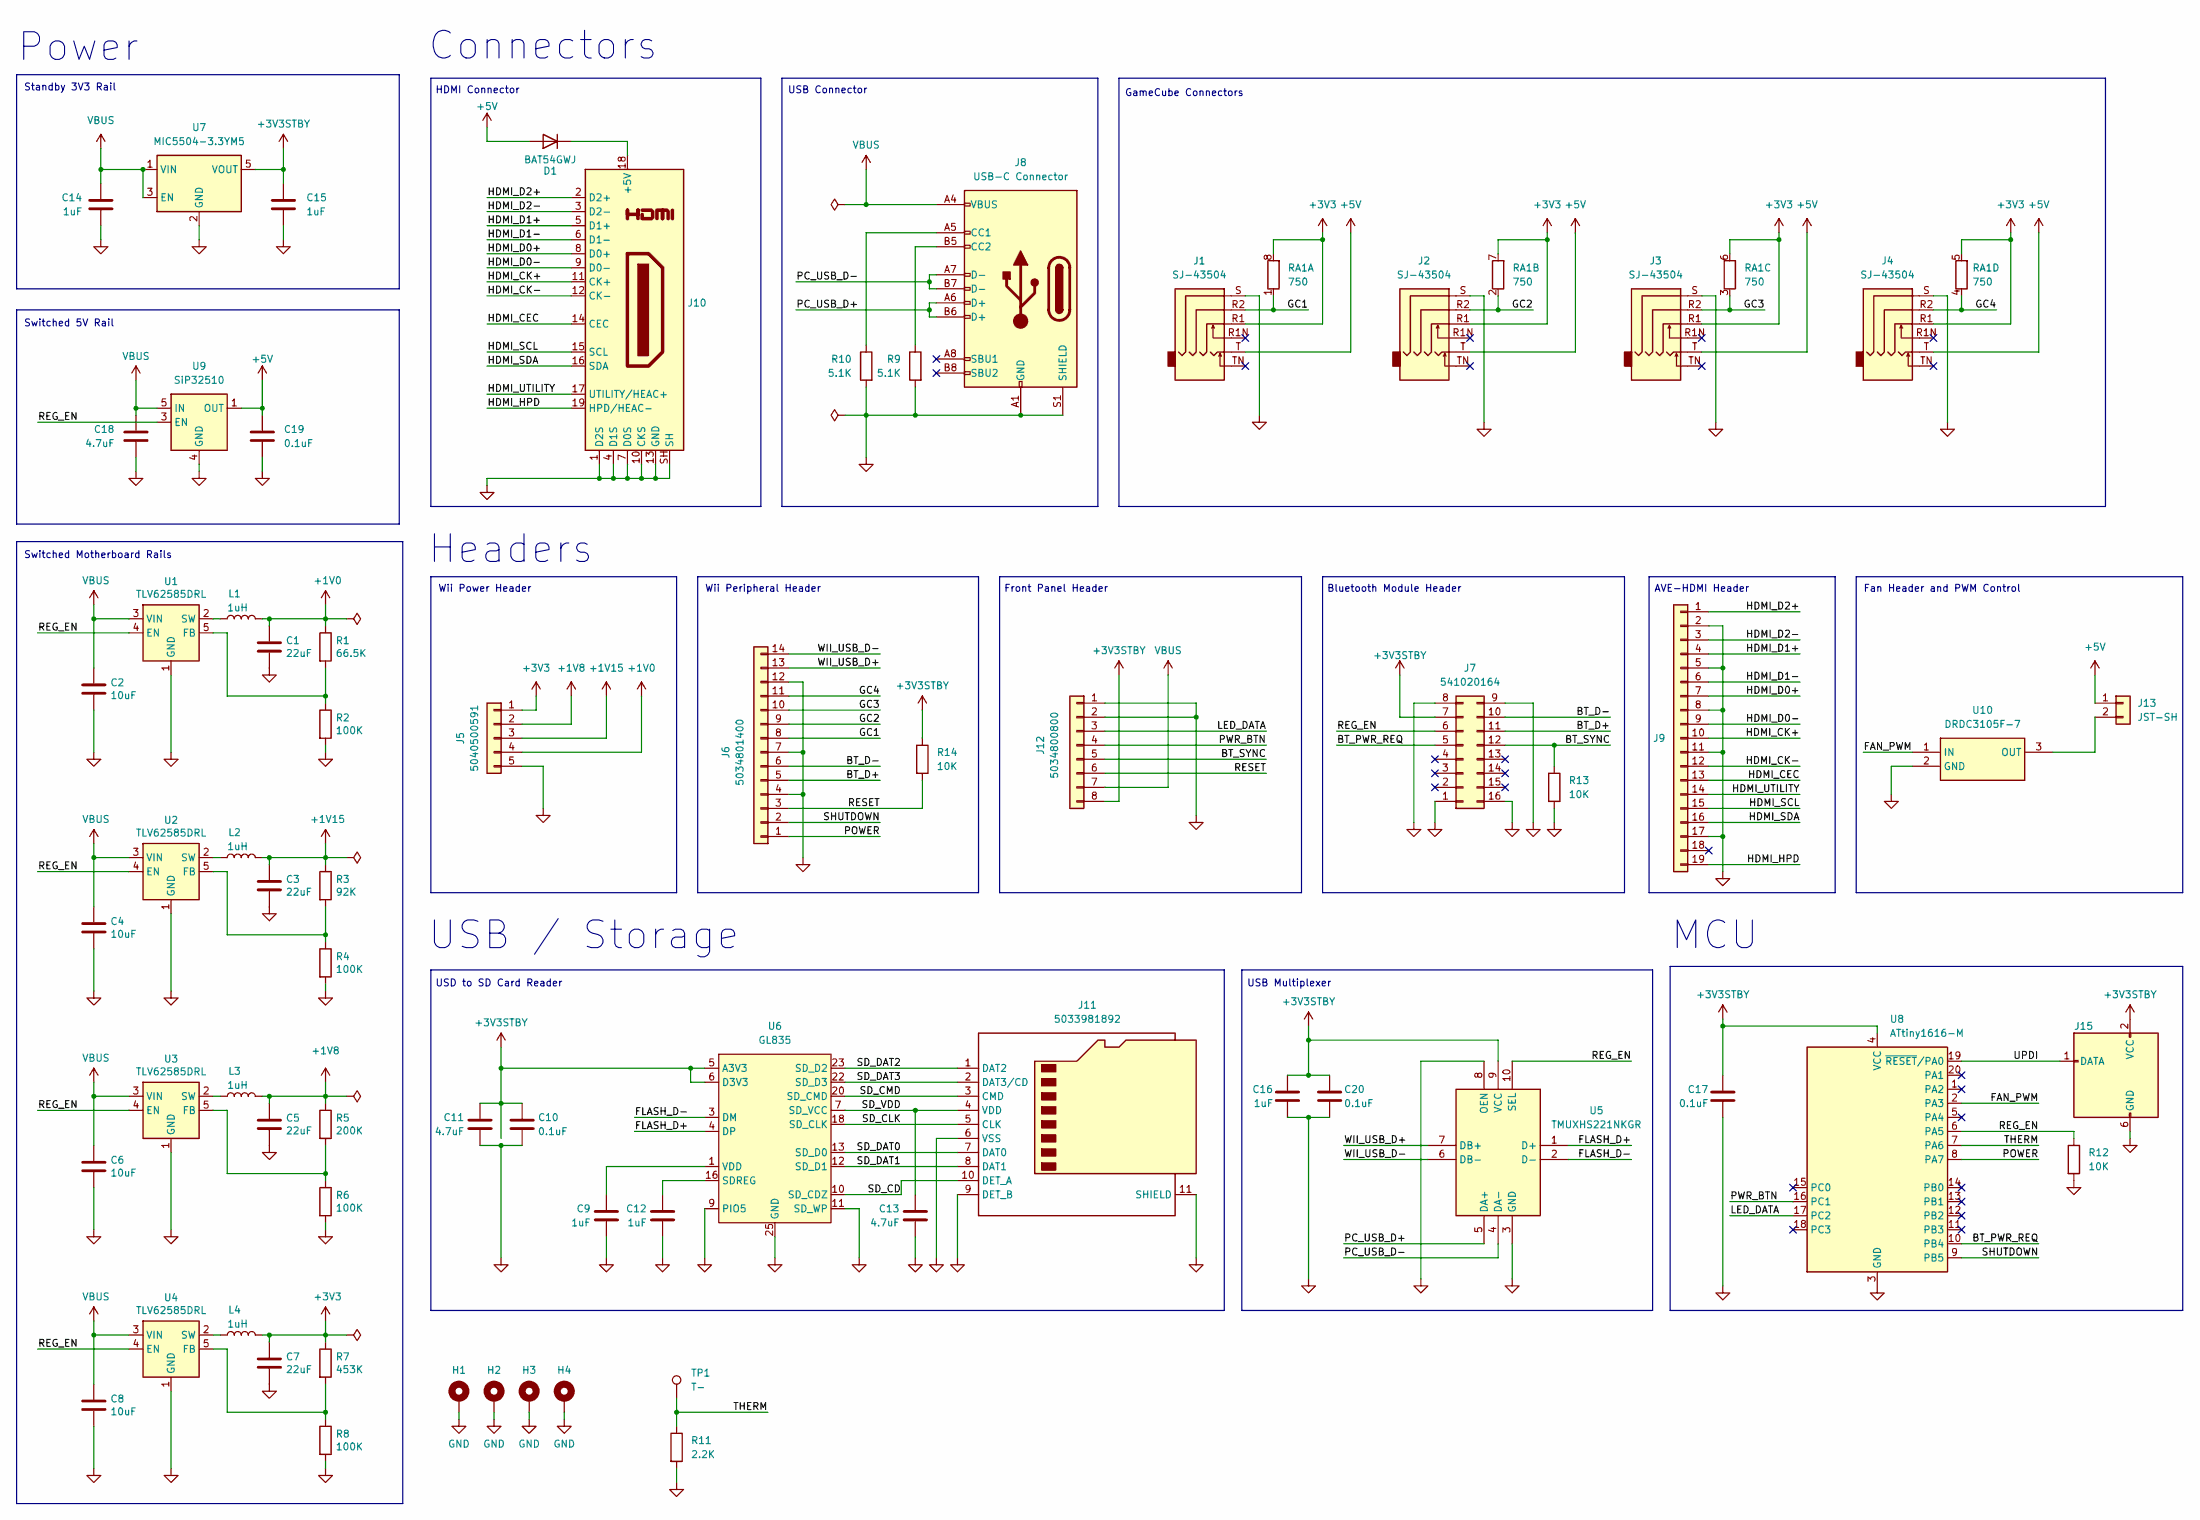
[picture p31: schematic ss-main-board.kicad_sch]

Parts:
C1, C3, C5, C7: 22uF; C_0805_2012Metric
C2, C4, C6, C8: 10uF; C_0805_2012Metric
C9, C12, C14, C15, C16: 1uF; C_0402_1005Metric
C10, C17, C19, C20: 0.1uF; C_0402_1005Metric
C11, C13, C18: 4.7uF; C_0402_1005Metric
D1: BAT54GWJ; D_SOD-123
H1, H2, H3, H4: MountingHole_Pad; MountingHole_2.7mm_M2.5_ISO7380_Pad_TopBottom
J1, J2, J3, J4: SJ-43504; SJ-43504-SMT-TR; MPN SJ-43504-SMT-TR; Digi-Key Part # CP-43504SJCT-ND
J5: 5040500591; MPN 5040500591; Digi-Key Part # WM24877CT-ND
J6: 5034801400; MPN 5034801200; Digi-Key Part # WM1441CT-ND
J7: 541020164; Wii_Bluetooth_Module; MPN 0541020164; Digi-Key Part # WM8876CT-ND
J8: USB-C Connector; MOLEX_2171790001; MPN 217179-0001; Digi-Key Part # 900-2171790001CT-ND
J9: AVE-HDMI Connector; 5052781933; MPN 5052781933; Digi-Key Part # 900-5052781933CT-ND
J10: HDMI_C_1.4; 20139781; MPN 2013978-1; Digi-Key Part # A107963CT-ND
J11: 5033981892; 503398-1892
J12: 5034800800; MPN 5014610812; Digi-Key Part # WM9076CT-ND
J13: JST-SH; JST_SH_SM02B-SRSS-TB_1x02-1MP_P1.00mm_Horizontal; MPN SM02B-SRSS-TB; Digi-Key Part # 455-SM02B-SRSS-TBCT-ND
J15: AVR-UPDI-6; UPDI Pads
L1, L2, L3, L4: 1uH; L_Vishay_IHLP-1212; MPN IHLP1212BZER1R0M11; Digi-Key Part # 541-1319-1-ND
R1: 66.5K; R_0402_1005Metric
R2, R4, R6, R8: 100K; R_0402_1005Metric
R3: 92K; R_0402_1005Metric
R5: 200K; R_0402_1005Metric
R7: 453K; R_0402_1005Metric
R9, R10: 5.1K; R_0402_1005Metric
R11: 2.2K; R_0402_1005Metric
R12, R13, R14: 10K; R_0402_1005Metric
RA1: 750; R_Array_Concave_4x0603
TP1: T-; TestPoint_Pad_D1.0mm
U1, U2, U3, U4: TLV62585DRL; SOTFL50P160X60-6N; MPN TLV62585DRLR; Digi-Key Part # 296-51694-1-ND
U5: TMUXHS221NKGR; Manufacturer_Part_Number TMUXHS221NKGR; Mouser Part Number 595-TMUXHS221NKGR
U6: GL835; QFN-24-1EP_4x4mm_P0.5mm_EP2.6x2.6mm
U7: MIC5504-3.3YM5; SOT-23-5; MPN MIC5504-3.3YM5-TR; Digi-Key Part # 576-4764-1-ND
U8: ATtiny1616-M; VQFN-20-1EP_3x3mm_P0.4mm_EP1.7x1.7mm
U9: SiP32510; TSOT-23-6
U10: DRDC3105F-7; SOT-23; Manufacturer_Part_Number DRDC3105F-7; Mouser Part Number 621-DRDC3105F-7

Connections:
+1V0: C1.1, J5.4, L1.2, R1.1
+1V8: C5.1, J5.2, L3.2, R5.1
+1V15: C3.1, J5.3, L2.2, R3.1
+3V3: C7.1, J1.R1, J2.R1, J3.R1, J4.R1, J5.1, L4.2, R7.1, RA1.5 (R4.2), RA1.6 (R3.2), RA1.7 (R2.2), RA1.8 (R1.2)
+3V3STBY: C10.1, C11.1, C15.1, C16.1, C17.1, C20.1, J7.7, J12.8, J15.2 (VCC), R14.1, U5.9 (VCC), U6.5 (A3V3), U6.6 (D3V3), U7.5 (VOUT), U8.4 (VCC)
+5V: C19.1, D1.2 (A), J1.T, J2.T, J3.T, J4.T, J13.1, U9.1 (OUT), U9.2 (OUT)
/BT_D+: J6.5, J7.11
/BT_D-: J6.6, J7.10
/BT_PWR_REQ: J7.5, U8.10 (PB4)
/BT_SYNC: J7.12, J12.5, R13.1
/FAN_PWM: U8.2 (PA3), U10.1 (IN)
/FLASH_D+: U5.1 (D+), U6.4 (DP)
/FLASH_D-: U5.2 (D-), U6.3 (DM)
/GC1: J1.R2, J6.8, RA1.1 (R1.1)
/GC2: J2.R2, J6.9, RA1.2 (R2.1)
/GC3: J3.R2, J6.10, RA1.3 (R3.1)
/GC4: J4.R2, J6.11, RA1.4 (R4.1)
/HDMI_CEC: J9.13, J10.14 (CEC)
/HDMI_CK+: J9.10, J10.11 (CK+)
/HDMI_CK-: J9.12, J10.12 (CK-)
/HDMI_D0+: J9.7, J10.8 (D0+)
/HDMI_D0-: J9.9, J10.9 (D0-)
/HDMI_D1+: J9.4, J10.5 (D1+)
/HDMI_D1-: J9.6, J10.6 (D1-)
/HDMI_D2+: J9.1, J10.2 (D2+)
/HDMI_D2-: J9.3, J10.3 (D2-)
/HDMI_HPD: J9.19, J10.19 (HPD/HEAC-)
/HDMI_SCL: J9.15, J10.15 (SCL)
/HDMI_SDA: J9.16, J10.16 (SDA)
/HDMI_UTILITY: J9.14, J10.17 (UTILITY/HEAC+)
/LED_DATA: J12.3, U8.17 (PC2)
/PC_USB_D+: J8.A6 (D+), J8.B6 (D+), U5.5 (DA+)
/PC_USB_D-: J8.A7 (D-), J8.B7 (D-), U5.4 (DA-)
/POWER: J6.1, U8.8 (PA7)
/PWR_BTN: J12.4, U8.16 (PC1)
/REG_EN: J7.6, R12.1, U1.4 (EN), U2.4 (EN), U3.4 (EN), U4.4 (EN), U5.10 (SEL), U8.6 (PA5), U9.3 (EN)
/RESET: J6.3, J12.6, R14.2
/SD_CD: J11.10 (DET_A), U6.10 (SD_CDZ)
/SD_CLK: J11.5 (CLK), U6.18 (SD_CLK)
/SD_CMD: J11.3 (CMD), U6.20 (SD_CMD)
/SD_DAT0: J11.7 (DAT0), U6.13 (SD_D0)
/SD_DAT1: J11.8 (DAT1), U6.12 (SD_D1)
/SD_DAT2: J11.1 (DAT2), U6.23 (SD_D2)
/SD_DAT3: J11.2 (DAT3/CD), U6.22 (SD_D3)
/SD_VDD: C13.1, J11.4 (VDD), U6.7 (SD_VCC)
/SHUTDOWN: J6.2, U8.9 (PB5)
/THERM: R11.1, TP1.1, U8.7 (PA6)
/UPDI: J15.1 (DATA), U8.19 (~RESET/PA0)
/WII_USB_D+: J6.13, U5.7 (DB+)
/WII_USB_D-: J6.14, U5.6 (DB-)
GND: C1.2, C2.2, C3.2, C4.2, C5.2, C6.2, C7.2, C8.2, C9.2, C10.2, C11.2, C12.2, C13.2, C14.2, C15.2, C16.2, C17.2, C18.2, C19.2, C20.2, H1.1, H2.1, H3.1, H4.1, J1.S, J2.S, J3.S, J4.S, J5.5, J6.4, J6.7, J6.12, J7.1, J7.8, J7.9, J7.16, J8.A1 (GND), J8.A12 (GND), J8.B1 (GND), J8.B12 (GND), J8.S1 (SHIELD), J9.2, J9.5, J9.8, J9.11, J9.17, J10.1 (D2S), J10.4 (D1S), J10.7 (D0S), J10.10 (CKS), J10.13 (GND), J10.SH, J11.6 (VSS), J11.9 (DET_B), J11.11 (SHIELD), J12.1, J12.2, J15.6 (GND), R2.2, R4.2, R6.2, R8.2, R9.2, R10.2, R11.2, R12.2, R13.2, U1.1 (GND), U2.1 (GND), U3.1 (GND), U4.1 (GND), U5.3 (GND), U5.8 (OEN), U6.9 (PIO5), U6.11 (SD_WP), U6.25 (GND), U7.2 (GND), U8.3 (GND), U8.21 (GND), U9.4 (GND), U10.2 (GND)
unnamed: D1.1 (K), J10.18 (+5V)
unnamed: J8.A5 (CC1), R10.1
unnamed: J8.B5 (CC2), R9.1
unnamed: J13.2, U10.3 (OUT)
unnamed: R1.2, R2.1, U1.5 (FB)
unnamed: L1.1, U1.2 (SW)
unnamed: R3.2, R4.1, U2.5 (FB)
unnamed: L2.1, U2.2 (SW)
unnamed: R5.2, R6.1, U3.5 (FB)
unnamed: L3.1, U3.2 (SW)
unnamed: R7.2, R8.1, U4.5 (FB)
unnamed: L4.1, U4.2 (SW)
unnamed: C12.1, U6.16 (SDREG)
unnamed: C9.1, U6.1 (VDD)
VBUS: C2.1, C4.1, C6.1, C8.1, C14.1, C18.1, J8.A4 (VBUS), J8.A9 (VBUS), J8.B4 (VBUS), J8.B9 (VBUS), J12.7, U1.3 (VIN), U2.3 (VIN), U3.3 (VIN), U4.3 (VIN), U7.1 (VIN), U7.3 (EN), U9.5 (IN), U9.6 (IN)

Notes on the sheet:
Wii Power Header
USB Multiplexer
HDMI Connector
AVE-HDMI Header
Power
Front Panel Header
Wii Peripheral Header
Standby 3V3 Rail
Connectors
USD to SD Card Reader
Bluetooth Module Header
Headers
GameCube Connectors
USB Connector
Fan Header and PWM Control
Switched 5V Rail
MCU
USB / Storage
Switched Motherboard Rails

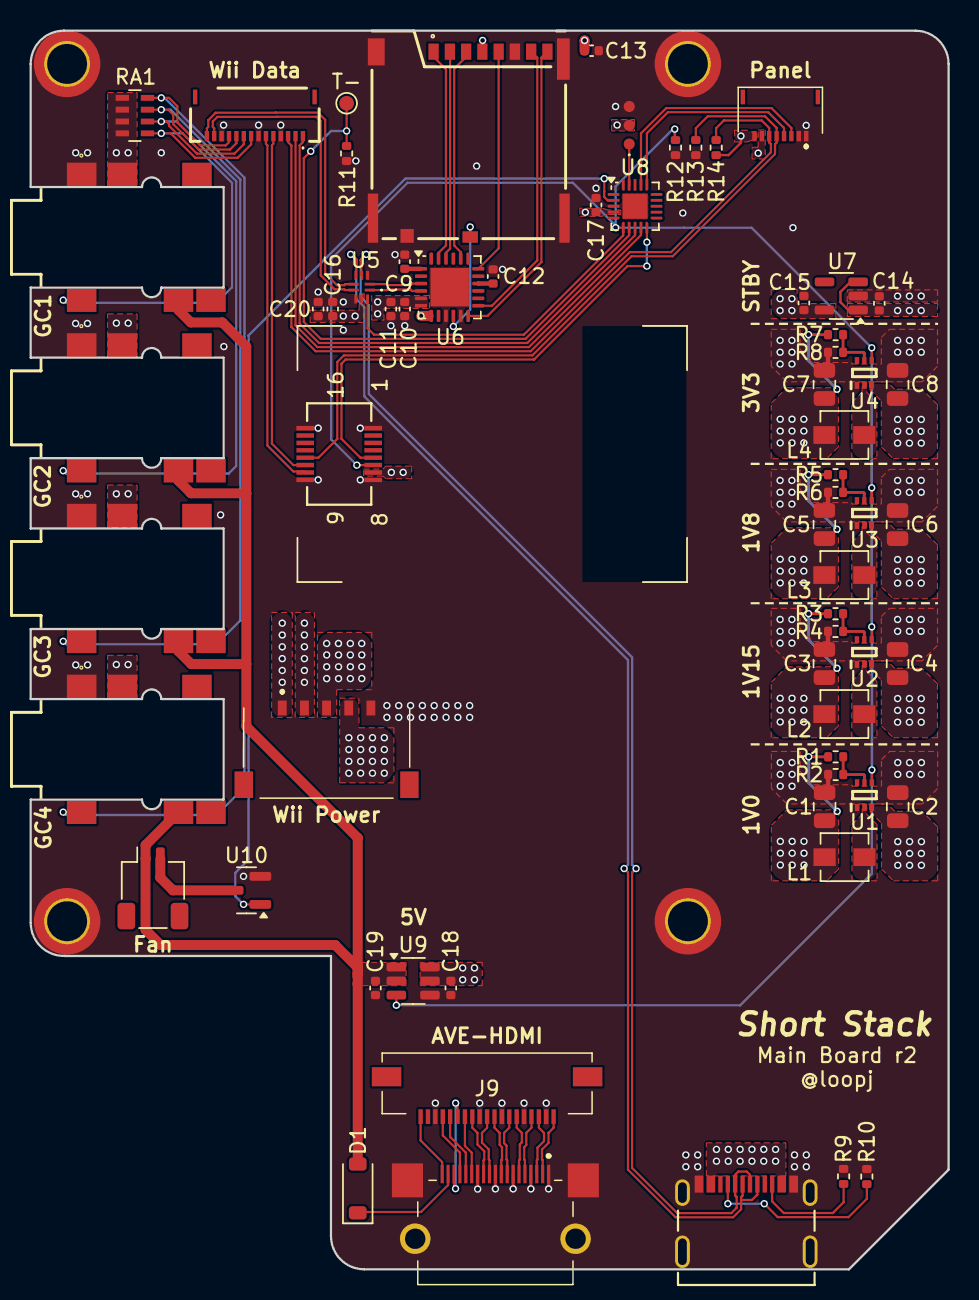
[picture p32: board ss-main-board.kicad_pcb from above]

Board: 4 copper layers, 62.1 x 83.8 mm, 69 parts (0 on the bottom side), 66 nets.

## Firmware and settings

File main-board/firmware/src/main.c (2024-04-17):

#include <avr/interrupt.h>
#include <avr/io.h>
#include <stdbool.h>

#include "events.h"
#include "gpio.h"
#include "led.h"
#include "rtc.h"

// GPIO definitions
static const gpio_t FAN_PWM    = {&PORTA, 3};
static const gpio_t REG_EN     = {&PORTA, 5};
static const gpio_t THERM      = {&PORTA, 6};
static const gpio_t POWER      = {&PORTA, 7};
static const gpio_t BT_PWR_REQ = {&PORTB, 4};
static const gpio_t SHUTDOWN   = {&PORTB, 5};
static const gpio_t PWR_BTN    = {&PORTC, 1};

// LED definitions
static const uint8_t POWER_LED  = 0;
static const uint8_t DISC_LED_L = 1;
static const uint8_t DISC_LED_R = 2;

// Output pulse timings
static const uint16_t POWER_PULSE_MS = 30;

// Button press thresholds
static const uint16_t BTN_PRESS_MS = 10;
static const uint16_t BTN_HOLD_MS  = 2000;

// Button states
enum button_state { BUTTON_RELEASED, BUTTON_PRESSED, BUTTON_HELD };

// Flags for events detected in interrupt handlers
enum event_flags { PWR_BTN_PRESS_EVENT, PWR_BTN_HOLD_EVENT, BT_PWR_REQ_EVENT, SHUTDOWN_EVENT };

// State
bool regs_enabled          = false;
bool power_pulse_active    = false;
uint32_t power_pulse_start = 0;

// Enable or disable the main regulators, updating the LEDs accordingly
void set_regulator_state(bool enabled)
{
    if (enabled) {
        // Turn on main regulators
        gpio_set_high(REG_EN);

        // Turn on the fan
        gpio_set_high(FAN_PWM);

        // Set power indicator LED to green, disc LEDs to cyan
        led_set_color(POWER_LED, 0x002000);
        led_set_color(DISC_LED_L, 0x00FFFF);
        led_set_color(DISC_LED_R, 0x00FFFF);
    } else {
        // Turn off main regulators
        gpio_set_low(REG_EN);

        // Turn off the fan
        gpio_set_low(FAN_PWM);

        // Set power indicator LED to red, turn off disc LEDs
        led_set_color(POWER_LED, 0x200000);
        led_set_color(DISC_LED_L, 0x000000);
        led_set_color(DISC_LED_R, 0x000000);
    }

    // Refresh the LEDs
    led_refresh();

    // Update state
    regs_enabled = enabled;
}

// Update the state of the power button
void update_pwr_btn_events()
{
    static bool last_gpio_state           = true;
    static uint32_t last_millis           = 0;
    static enum button_state button_state = BUTTON_RELEASED;

    // Read the current state of the power button (active low)
    bool gpio_state = gpio_read(PWR_BTN);

    // Reset hold time and flags if the button state has changed
    uint32_t millis = rtc_millis();
    if (gpio_state != last_gpio_state) {
        last_millis  = millis;
        button_state = BUTTON_RELEASED;
    }

    // If the button is down, check for hold time thresholds
    if (gpio_state == false) {
        // Raise event flags when hold time thresholds are reached
        if (millis - last_millis >= BTN_PRESS_MS && button_state < BUTTON_PRESSED) {
            button_state = BUTTON_PRESSED;
            event_set(PWR_BTN_PRESS_EVENT);
        } else if (millis - last_millis >= BTN_HOLD_MS && button_state < BUTTON_HELD) {
            button_state = BUTTON_HELD;
            event_set(PWR_BTN_HOLD_EVENT);
        }
    }

    // Save the current state for comparison next time
    last_gpio_state = gpio_state;
}

// Send a pulse to the POWER GPIO to request a soft shutdown
void send_power_pulse()
{
    gpio_set_high(POWER);
    power_pulse_active = true;
    power_pulse_start  = rtc_millis();
}

// Clear the POWER GPIO if the pulse has been active for the required time
void clear_completed_power_pulse()
{
    if (power_pulse_active && rtc_millis() - power_pulse_start >= POWER_PULSE_MS) {
        gpio_set_low(POWER);
        power_pulse_active = false;
    }
}

// Disable the prescaler to run the CPU at full speed
void clk_disable_prescaler()
{
    CPU_CCP = CCP_IOREG_gc;
    CLKCTRL.MCLKCTRLB &= ~CLKCTRL_PEN_bm;
}

// Initialize the GPIOs
void gpio_init()
{
    // Power button input (active low on button press)
    gpio_input(PWR_BTN);
    gpio_config(PWR_BTN, PORT_PULLUPEN_bm);

    // Bluetooth power request input (active high, ~110ms pulse)
    gpio_input(BT_PWR_REQ);
    gpio_config(BT_PWR_REQ, PORT_ISC_RISING_gc);

    // Soft shutdown complete input (active high, ~120ms pulse)
    gpio_input(SHUTDOWN);
    gpio_config(SHUTDOWN, PORT_ISC_RISING_gc);

    // Regulator enable output
    gpio_output(REG_EN);

    // Soft shutdown request output
    gpio_output(POWER);

    // Fan power output
    gpio_output(FAN_PWM);
}

// Handle external interrupts on PORTB
ISR(PORTB_PORT_vect)
{
    // Check for "bluetooth power request" pulse
    if (gpio_read_intflag(BT_PWR_REQ)) {
        event_set(BT_PWR_REQ_EVENT);
    }

    // Check for "soft shutdown complete" pulse
    if (gpio_read_intflag(SHUTDOWN)) {
        event_set(SHUTDOWN_EVENT);
    }

    // Clear the interrupt flags
    PORTB.INTFLAGS = 0xFF;
}

int main()
{
    // Initialize the RTC with a 1ms periodic interrupt
    // We need this to measure power button press and hold times, and to time output pulses
    rtc_init();

    // Initialize the GPIOs
    gpio_init();

    // Initialize the addressable LEDs
    led_init();

    // Disable the prescaler to run the CPU at full speed
    // Required for accurate bit-banging of LEDs
    clk_disable_prescaler();

    // Enable global interrupts
    sei();

    // Set the initial state of the main regulators to off
    set_regulator_state(false);

    // Main loop
    while (true) {
        // Check for power button events (press, hold)
        update_pwr_btn_events();

        // Check for completed power pulses, and turn off the POWER gpio if necessary
        clear_completed_power_pulse();

        // Handle power button presses
        if (event_get(PWR_BTN_PRESS_EVENT)) {
            if (regs_enabled) {
                // Send a soft shutdown request pulse to Hollywood
                send_power_pulse();
            } else {
                // Turn on the main regulators if they are off
                set_regulator_state(true);
            }
        }

        // Turn off the main regulators if the power button is held for 2 seconds
        if (event_get(PWR_BTN_HOLD_EVENT)) {
            if (regs_enabled)
                set_regulator_state(false);
        }

        // Handle bluetooth power request pulses
        if (event_get(BT_PWR_REQ_EVENT)) {
            if (regs_enabled) {
                // Send a soft shutdown request pulse to Hollywood
                send_power_pulse();
            } else {
                // Turn on the main regulators if they are off
                set_regulator_state(true);
            }
        }

        // Turn off the main regulators if Hollywood indicates a soft shutdown is complete
        if (event_get(SHUTDOWN_EVENT)) {
            if (regs_enabled)
                set_regulator_state(false);
        }
    }

    return 0;
}

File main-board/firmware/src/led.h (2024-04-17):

/**
 * Quick and dirty addressable LED library for AVR 0/1-series MCUs
 *
 * - Bit-bangs data to addressable LEDs
 * - Supports 1 wire addressable LEDs with WS2812B-ish protocols
 * - Supports a single chain of LEDs
 */

#pragma once

#include <stdint.h>

// LED layout configuration
#define LED_COUNT 3 // Number of LEDs in the chain
#define LED_BYTES 3 // Number of bytes per LED (eg. 3 for RGB)

// LED timing configuration (values in microseconds)
// Everlight 19-C47 / 12-23C LEDs
// https://jp.everlight.com/wp-content/uploads/2021/02/One-Wire-RGBIC-Application-note-V1.0EN.pdf
#define LED_T0H 0.3
#define LED_T0L 0.9
#define LED_T1H 0.9
#define LED_T1L 0.3
#define LED_LAT 50

// LED data pin configuration
#define LED_PORT PORTC
#define LED_PIN  2

// Initialize the LED data pin
void led_init();

// Set the color of an LED in the buffer
void led_set_color(uint8_t index, uint32_t color);

// Refresh the LEDs with the current buffer
void led_refresh();

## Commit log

2024-04-18 Fix case side step file
    [case-side.step]
2024-04-18 Add missing button cad file
    [button.step]
2025-03-31 Add missing 19-pin hdmi ffc to BOM
    [full-bom.xlsx]
